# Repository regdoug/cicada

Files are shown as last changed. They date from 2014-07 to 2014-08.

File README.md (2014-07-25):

# Project CiCADA

Project CiCADA is an experiment to design an inexpensive interactive 3D display.
It was developed by Mike Rodriguez as part of his Masters degree in Manufacturing
and Mechanical Systems Integration at Rochester Institute of Technology

## Code

Firmware code for the Arduino Mega 2560 that interfaces with the hardware is in
the `arduino` folder.

In the `python` folder, the `cicada` module provides an abstract interface to the
hardware.  The example applications provided use the `cicada` module.

## CAD

SolidWorks, STEP, and STL files are provided in the `cad` folder. The prototype
was printed on a Stratasys U-Print and a Stratasys (something else...)

## Licensing

Code under the `arduino` and `python` folder is licensed under GPLv3.
Solid models are distributed under the Creative Commons Attribution (CC-BY 3.0).

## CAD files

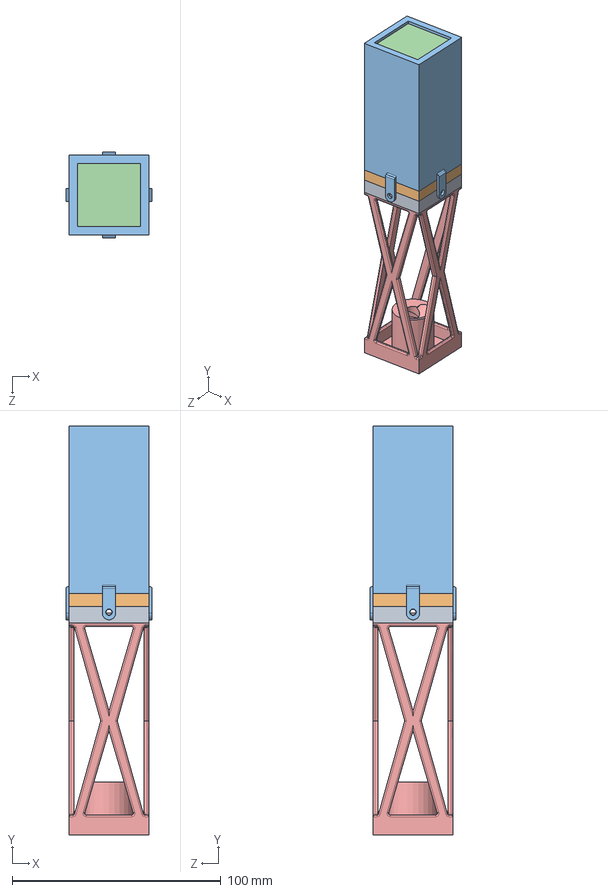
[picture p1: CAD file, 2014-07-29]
cad/solidworks/Pin_Assembly.SLDASM
41.3 x 195.9 x 41.3 mm
Lower_Pin_Upper
Board_Plate
Upper_Pin
Pin_Surface
Lower_Pin_Lower_V3

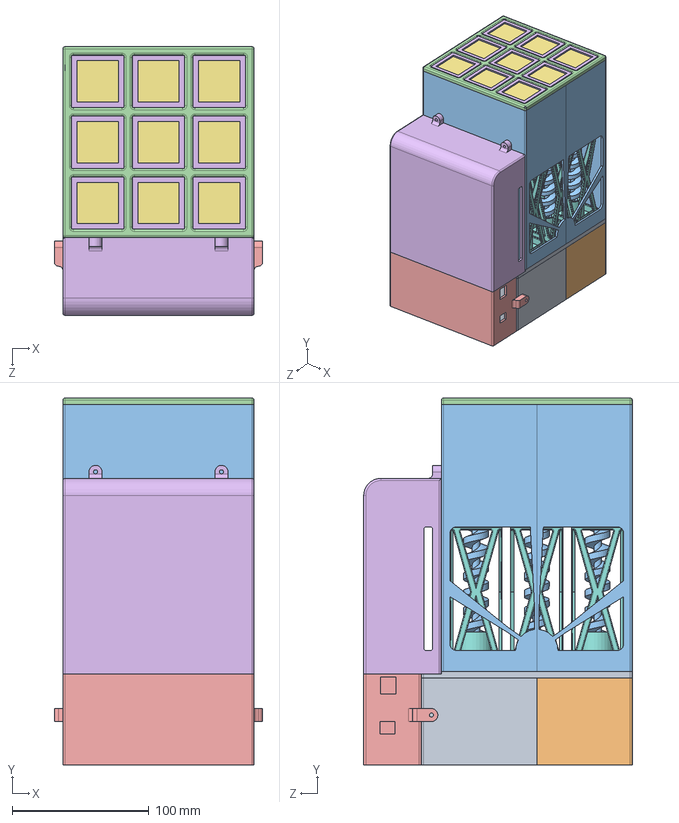
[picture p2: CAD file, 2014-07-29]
cad/solidworks/POC_FINAL.SLDASM
152.4 x 268.3 x 196.4 mm
Baseplate
StepMotor28BYJ x 9
Power_Screw x 9
Lower_Pin_Upper x 9
Board_Plate x 9
Upper_Pin x 9
Pin_Surface x 9
Lower_Pin_Lower_V3 x 9
Housing_Base_Female
Housing_Base_Male
Housing_Pin_Half x 2
Housing_Pin_Roof
Electronics_Mounting_Plate_Lower
Electronics_Mounting_Plate_Upper

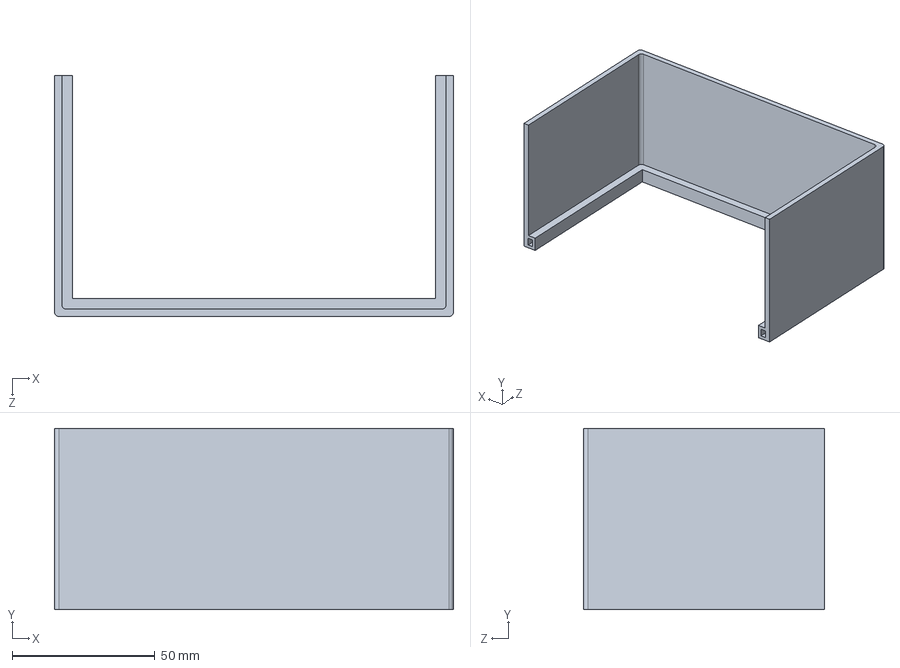
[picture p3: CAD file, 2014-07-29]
cad/solidworks/Housing_Base_Female.SLDPRT
139.7 x 63.5 x 84.4 mm

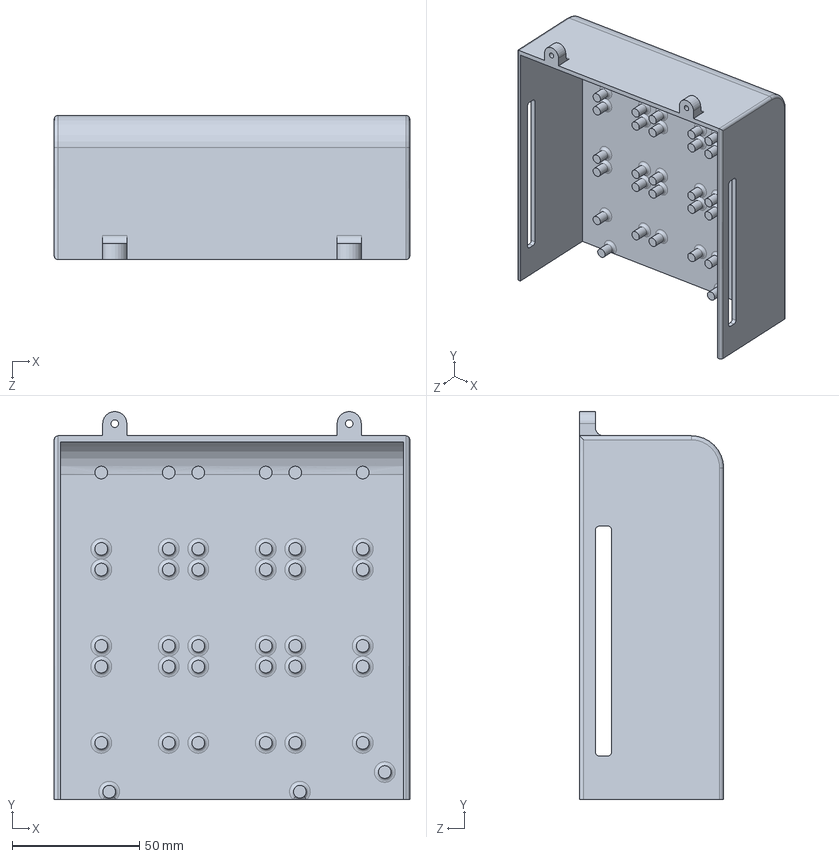
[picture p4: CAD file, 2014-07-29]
cad/solidworks/Electronics_Mounting_Plate_Upper.SLDPRT
139.7 x 152.4 x 56.7 mm

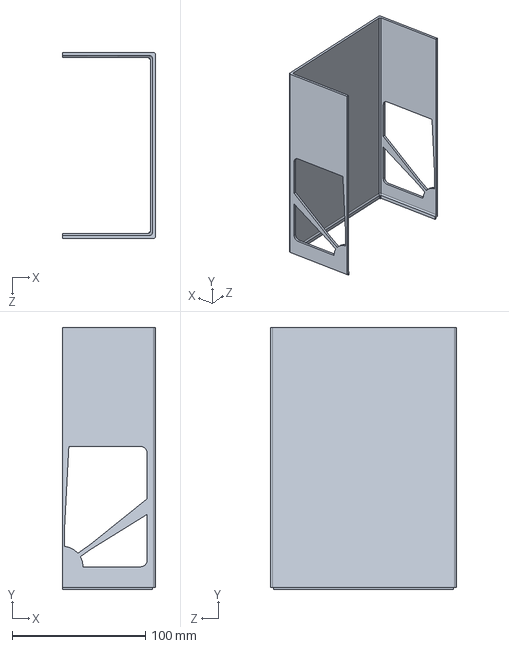
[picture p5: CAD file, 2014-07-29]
cad/solidworks/Housing_Pin_Half.SLDPRT
69.8 x 196.8 x 139.7 mm

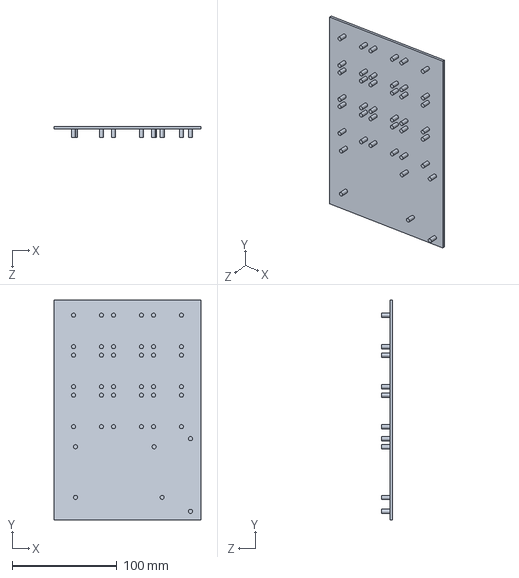
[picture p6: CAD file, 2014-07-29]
cad/solidworks/Electronics_Mounting_Plate.SLDPRT
139.7 x 209.5 x 10.5 mm

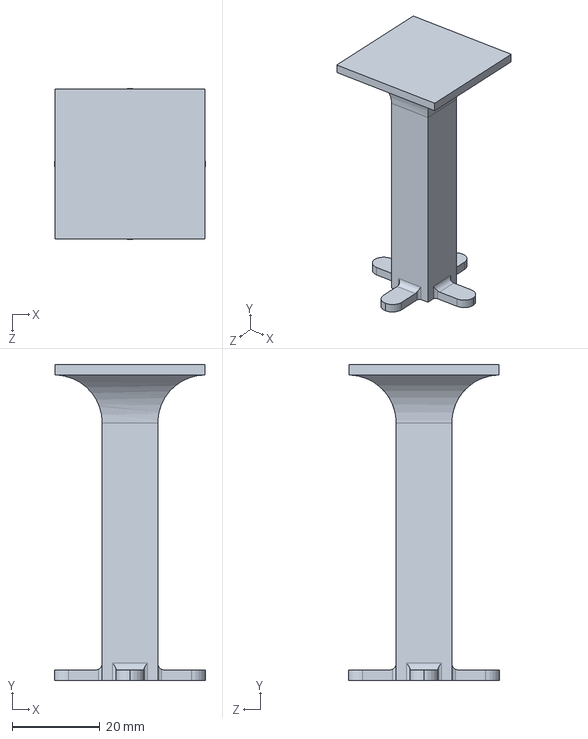
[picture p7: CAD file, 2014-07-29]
cad/solidworks/Pin_Surface.SLDPRT
34.5 x 72.1 x 34.5 mm

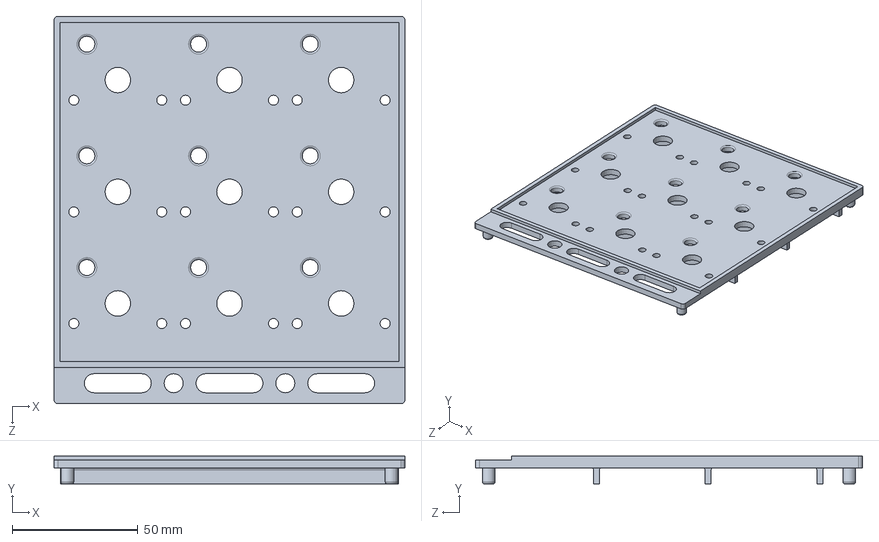
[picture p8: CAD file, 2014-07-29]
cad/solidworks/Baseplate.SLDPRT
139.7 x 11.1 x 154.2 mm

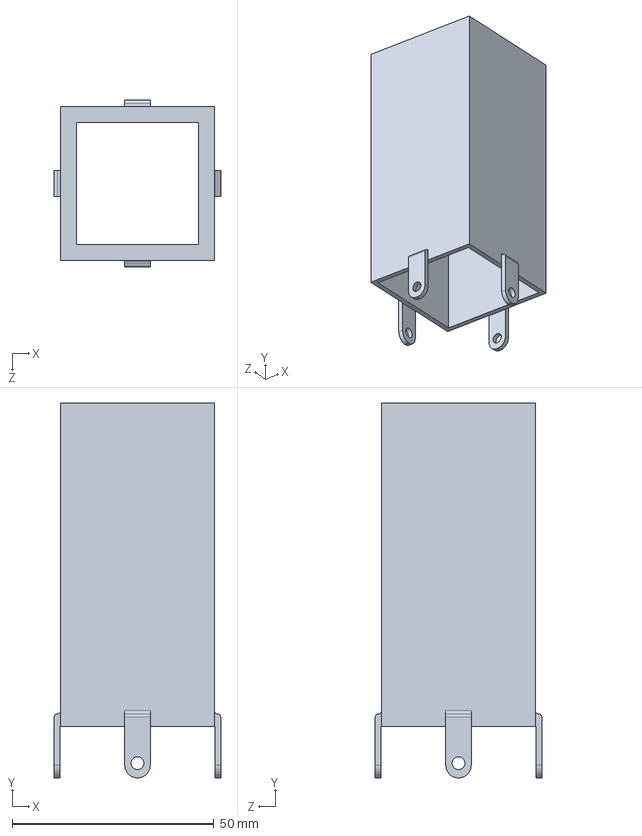
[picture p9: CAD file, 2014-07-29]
cad/solidworks/Upper_Pin.SLDPRT
41.3 x 92.9 x 41.3 mm

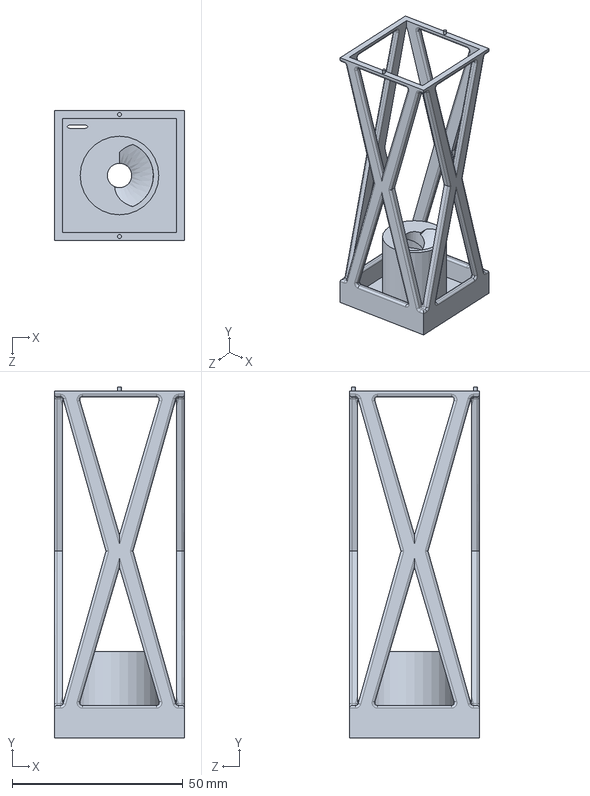
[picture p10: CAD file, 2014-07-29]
cad/solidworks/Lower_Pin_Lower.SLDPRT
38.1 x 102.8 x 38.1 mm

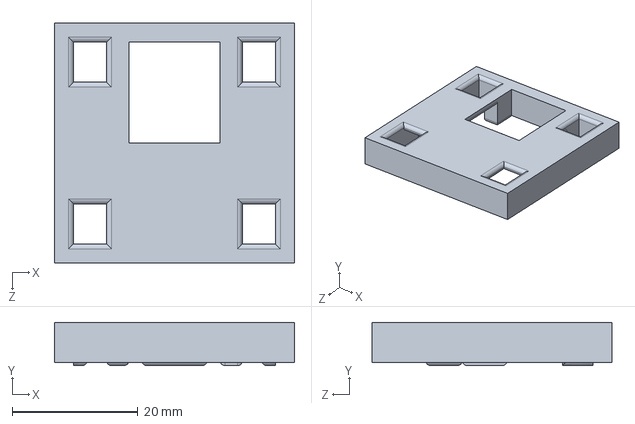
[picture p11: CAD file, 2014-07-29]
cad/solidworks/Board_Plate.SLDPRT
38.1 x 6.86 x 38.1 mm

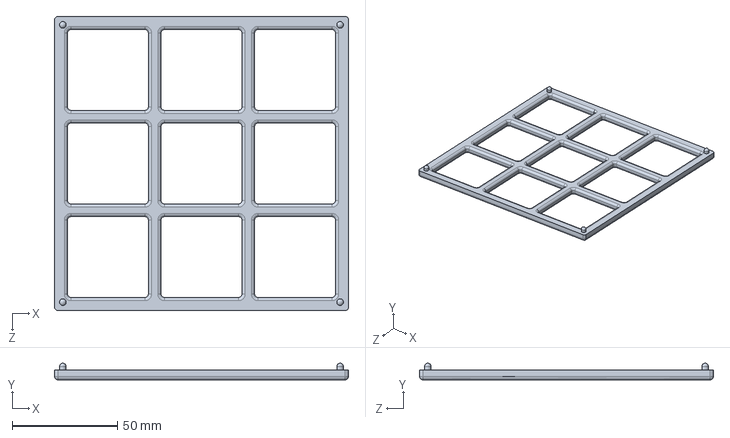
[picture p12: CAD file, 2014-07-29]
cad/solidworks/Housing_Pin_Roof.SLDPRT
139.7 x 7.94 x 139.7 mm

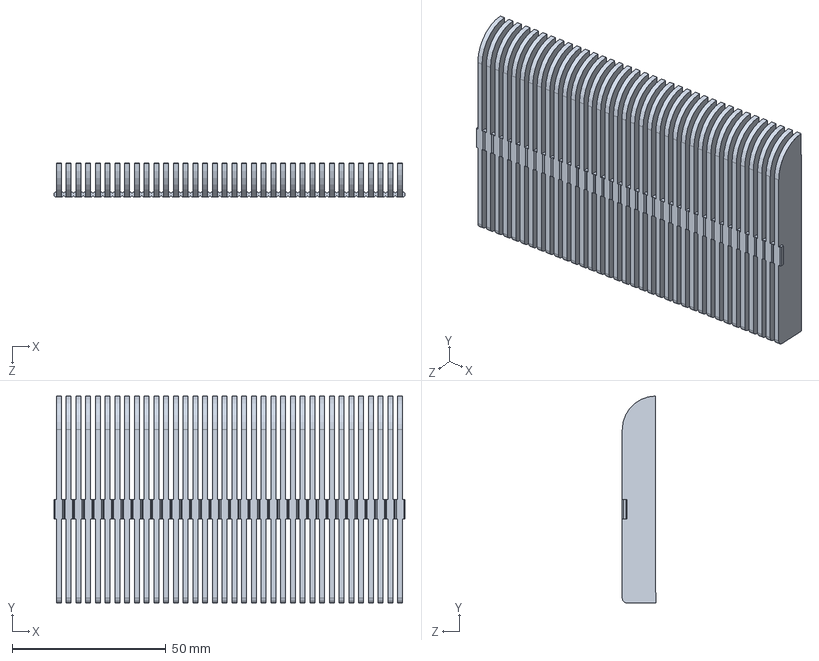
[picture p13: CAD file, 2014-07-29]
cad/solidworks/Pin_Separators.SLDPRT
114.3 x 67.4 x 10.9 mm

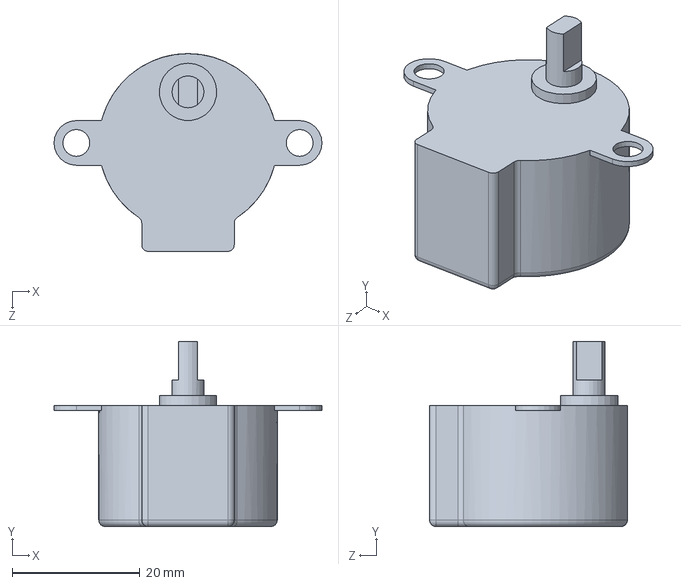
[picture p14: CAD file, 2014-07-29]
cad/solidworks/StepMotor28BYJ.SLDPRT
42.0 x 29.0 x 31.0 mm

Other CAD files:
cad/solidworks/Lower_Pin_Upper.SLDPRT
cad/solidworks/Housing_Base_Male.SLDPRT
cad/solidworks/Electronics_Mounting_Plate_Lower.SLDPRT
cad/solidworks/Power_Screw.SLDPRT
cad/stl/Baseplate.STL
cad/stl/Board_Plate.STL
cad/stl/Electronics_Mounting_Plate_Lower.STL
cad/stl/Electronics_Mounting_Plate_Upper.STL
cad/stl/Housing_Base_Female.STL
cad/stl/Housing_Base_Male.STL
cad/stl/Housing_Pin_Half.STL
cad/stl/Housing_Pin_Roof.STL
cad/stl/Lower_Pin_Lower.STL
cad/stl/Lower_Pin_Upper.STL
cad/stl/Pin_Separators.STL
cad/stl/Pin_Surface.STL
cad/stl/Power_Screw.STL
cad/stl/Upper_Pin.STL

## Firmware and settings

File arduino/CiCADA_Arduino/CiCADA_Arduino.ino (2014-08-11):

// Initiate buttons to I/O pins, initiate ShiftPWM latch pin, invert for common anode LEDs
const int buttons [9] = {4, 19, 3, 14, 20, 16, 17, 15, 18};
const int ShiftPWM_latchPin=53;
const bool ShiftPWM_invertOutputs = true; 
const bool ShiftPWM_balanceLoad = false;

// Define speed and target multipliers in order to translate incoming bytes (0-255) to proper ranges
const int SPD_MULT = 2;
const int TARGET_MULT = 323;

// 
int buf[5] = { 0, 0, 0, 0, 0 };
int buf_ptr = 0;

// Set boolean active, include ShiftPWM and AccelStepper libraries
boolean active = true;
#include <ShiftPWM.h>
#include <AccelStepper.h>

// Set maxBrightness to 2 (allows LEDs to actually turn mostly off), pwmFrequency (maximum refresh before noticeable lag), set the number of shift registers to 18
unsigned char maxBrightness = 2;
unsigned char pwmFrequency = 120;
int numRegisters = 18;

// Define the number of stepper motors, initiate data storage array (H = height, S = speed)
AccelStepper steppers[9];
//                Hs1  Ss1  Hs2  Ss2  Hs3  Ss3  Hs4  Ss4  Hs5  Ss5  Hs6  Ss6  Hs7  Ss7  Hs8  Ss8  Hs9  Ss9   
long data[18] = {   0, 410,   0, 410,   0, 410,   0, 410,   0, 410,   0, 410,   0, 410,   0, 410,   0, 410};

// Initiate button state storage array
int buttonState[9] = { LOW, LOW, LOW, LOW, LOW, LOW, LOW, LOW, LOW};

// Define led, stepper, zero objects
void led(byte idx, byte r, byte g, byte b);
void stepper(byte idx, long target, long spd);
void zero();

void setup(){
  
  for( int i =0; i<9; i++)
  {
  pinMode(buttons[i],INPUT_PULLUP);
  }
  
steppers[0] = AccelStepper(AccelStepper::FULL4WIRE, 22, 24, 23, 25);
steppers[1] = AccelStepper(AccelStepper::FULL4WIRE, 26, 28, 27, 29);
steppers[2] = AccelStepper(AccelStepper::FULL4WIRE, 30, 32, 31, 33);
steppers[3] = AccelStepper(AccelStepper::FULL4WIRE, 34, 36, 35, 37);
steppers[4] = AccelStepper(AccelStepper::FULL4WIRE, 38, 40, 39, 41);
steppers[5] = AccelStepper(AccelStepper::FULL4WIRE, 42, 44, 43, 45);
steppers[6] = AccelStepper(AccelStepper::FULL4WIRE, 12, 10, 11, 9);
steppers[7] = AccelStepper(AccelStepper::FULL4WIRE, 8, 6, 7, 5);
steppers[8] = AccelStepper(AccelStepper::FULL4WIRE, 46, 48, 47, 49);

for( int i = 0; i < 9; i++ )
{
steppers[i].setMaxSpeed(410);
steppers[i].setAcceleration(0);
}    
    
  Serial.begin(9600);
  ShiftPWM.SetAmountOfRegisters(numRegisters);
  ShiftPWM.SetPinGrouping(1);
  ShiftPWM.Start(pwmFrequency,maxBrightness);
       
}

void serialEvent()
{
  byte b = 0;
  while(Serial.available())
  {
    b = Serial.read();
    if(255 == b)
    {
      switch( buf[0] )
      {
        case 0: led(buf[1],buf[2],buf[3],buf[4]);break;
        case 1: stepper(buf[1],buf[2],buf[3]);break;
        case 2: stepper(buf[1],-buf[2],buf[3]);break;
        case 3: zero(); break;
        default: break;
      }
      buf_ptr = 0;
    }
    else
    {
      buf[buf_ptr] = b;
      buf_ptr = (buf_ptr + 1)%5;
    }
  }
}

void loop()
{    
  boolean done = true;
  int currentState;
  for(int i=0; i<9; i++)
  {
    currentState = digitalRead(buttons[i]);
    if( currentState != buttonState[i])
    {
      if( currentState == HIGH)
      {
        Serial.write(255-i);
      }
      else
      {
        Serial.write(i);
      }
    }
    buttonState[i] = currentState;
if( buttonState[i] == HIGH )
{
steppers[i].moveTo(data[i*2]);
steppers[i].setSpeed(data[i*2+1]);
if( steppers[i].distanceToGo()==0)
{
steppers[i].disableOutputs();
}
else
{
steppers[i].enableOutputs();
steppers[i].runSpeedToPosition();
done = false;
active = true;
}
}
  }
if( done == true && active==true)
{
Serial.write(128);
active = false;
}
}

void led(byte idx, byte r, byte g, byte b)
{
  int offset = idx*3+2*((idx*3)/6);
  ShiftPWM.SetOne (offset, r);
  ShiftPWM.SetOne (offset+1, g);
  ShiftPWM.SetOne (offset+2, b);
}
void stepper(byte idx, long target, long spd)
{
  data[idx*2] = target*TARGET_MULT;
  data[idx*2+1] = spd*SPD_MULT;
}
void zero()
{
  for(int i=0; i<9; i++)
  {
    steppers[i].setCurrentPosition(0);
  }
}

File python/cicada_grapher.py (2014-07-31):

import cicada
import serial
from time import sleep
from pyxll import xl_func
from multiprocessing.connection import Client
import numpy as np

address = ('localhost', 6000)    
listener = Listener(address, authkey='secret password')
conn = listener.accept()
print 'connection accepted from', listener.last_accepted
data = []
while True:
    msg = conn.recv()
    if msg == 'close':
        conn.close()
        break
    else:    
        data.append(msg)

listener.close()

data = np.array(data)
max_pos = np.max(data[:,1])
min_pos = np.min(0,np.min(data[:,1]))

data[:,1] = ((33/(max_pos-min_pos))*(data[:,1]-min_pos))

for row in data:
    c[row[0]].go_to(row[1],205)
    if row[2] == 'red':
        color = (254,0,0)
    elif row[2] == 'green':
        color = (0, 254, 0)
    elif row[2] == 'blue':
        color = (0, 0, 254)
    elif row[2] == 'yellow':
        color = (254, 254, 0)
    elif row[2] == 'purple':
        color = (254, 0, 254)
    elif row[2] == 'cyan':
        color = (0, 254, 254)
    elif row[2] == 'white':
        color = (254, 254, 254)
    elif row[2] == 'orange':
        color = (254, 128, 0)
    else:
        color = (0, 0, 0)
    c[row[2]].set_color(color)

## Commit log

2014-07-25 Initial commit: basic functionality written
    This code has not been tested
    TODO:
    - figure out how to write Pythonic event handlers/callback fcns
    and use that to respond to button events
    - check that serial signals are correct.
    [cicada.py]
2014-07-27 Interface changes
    - Changed `zero` to `tare`
    - Added utility to get currently press duration for each pin
2014-07-27 Added observers for events.
    Observers should accept 3 arguments: event type, pin index, and
    data. Right now the event type can only be `'button'`. The data
    for button events is the new button state (1 for pressed, 0 for
    unpressed)
2014-07-29 Created applications
    grapher.py - unfinished, untested
    jog.py - finished, some issues with pin 0
    mouse.py - library for controlling mouse. Doesn't run in Python 3
    mouser.py - unfinished
    simon.py - tested, may add some feature in future
    zero.py - tested, works.
    [grapher.py, jog.py, mouse.py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]
2014-07-29 Arduino driver for CiCADA
2014-07-29 solidworks and .stl files
    [Baseplate.SLDPRT, Baseplate.STL, Board_Plate.SLDPRT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]
2014-07-31 Multiple Changes
    Added cicada_grapher - recieve data from grapher and send to cicada
    grapher - created function using pyxll to take arrays pin number,
    position, and color and send to cicada_grapher. "Bar graph exporter".
    pyxll will not open in excel
    jog - fixed bugs
    mouse - fixed and completed
    mouser - fixed
    simon - added sound and removed cheat
    startup - combined zero and jog. may add startup animation.
    [cicada.py, cicada_grapher.py, grapher.py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]
2014-08-11 Finalized Applications and Edits Made
    Arduino file placed in sketchbook folder
    cicada: Pins now referred to as Voxels
    grapher completed, files:
    - CiCADA_Grapher_Example.xlsm
    - grapher.py
    - grapher.csv
    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
    [CiCADA_Grapher_Example.xlsm, grapher.csv]
